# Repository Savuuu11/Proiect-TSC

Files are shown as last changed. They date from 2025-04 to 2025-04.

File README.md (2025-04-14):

# E-book Reader Open-Source
Savu Alin Ion 332CC

### Diagrama

---

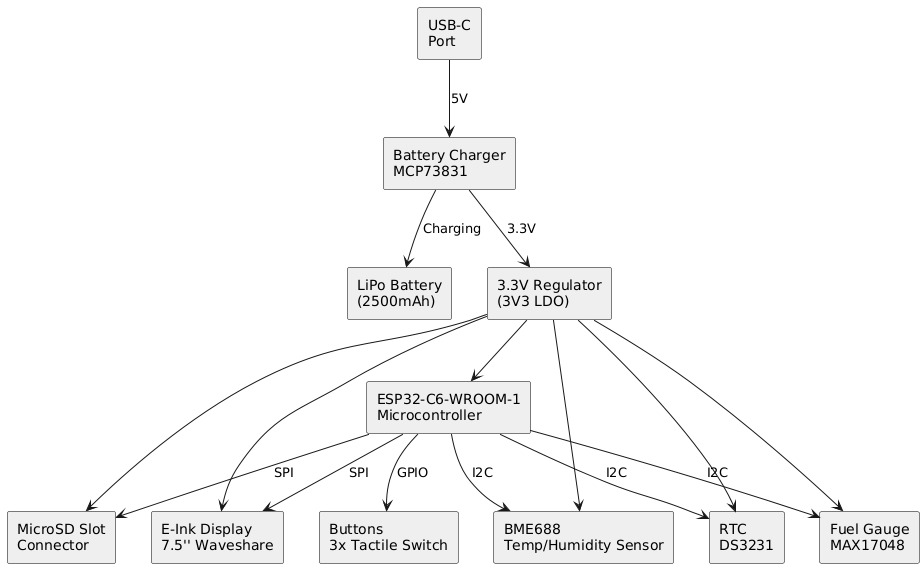
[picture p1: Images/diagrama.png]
Hardware Diagram


### BOM - Bill of Materials

---

| Name of component | Device | Check Prices | DataSheet |
|---|---|---|---|
| BOOT_BUTTON | BUTTON_CUSYOMV1 | [Link](https://industry.panasonic.com/global/en/products/control/switch/light-touch/number/evqpuj02k) | [Link](https://industry.panasonic.com/global/en/products/control/switch/light-touch/number/evqpuj02k) |
| C1 | ESP32_WROVER_EAGLE-LTSPICE_CC0402 | [Link](https://industry.panasonic.com/global/en/products/control/switch/light-touch/number/evqpuj02k) | [Link](https://industry.panasonic.com/global/en/products/control/switch/light-touch/number/evqpuj02k) |
| C1_BAT | ESP32_WROVER_EAGLE-LTSPICE_CC0402 | #N/A | #N/A |
| C1_BAT1 | EAGLE-LTSPICE_CC0402 | #N/A | #N/A |
| C1_BAT2 | EAGLE-LTSPICE_CC0402 | #N/A | #N/A |
| C2 | ESP32_WROVER_EAGLE-LTSPICE_CC0402 | #N/A | #N/A |
| C2_BAT\ | ESP32_WROVER_EAGLE-LTSPICE_CC0402 | #N/A | #N/A |
| C3 | RCL_CPOL-EUCT3528 | #N/A | #N/A |
| C4 | ESP32_WROVER_EAGLE-LTSPICE_CC0402 | #N/A | #N/A |
| C4_USB | ESP32_WROVER_EAGLE-LTSPICE_CC0402 | #N/A | #N/A |
| C5 | ESP32_WROVER_EAGLE-LTSPICE_CC0402 | #N/A | #N/A |
| C5_USB | ESP32_WROVER_EAGLE-LTSPICE_CC0402 | #N/A | #N/A |
| C6 | ESP32_WROVER_EAGLE-LTSPICE_CC0402 | #N/A | #N/A |
| C7 | ESP32_WROVER_EAGLE-LTSPICE_CC0402 | #N/A | #N/A |
| C8 | ESP32_WROVER_EAGLE-LTSPICE_CC0402 | #N/A | #N/A |
| C9 | EAGLE-LTSPICE_CC0402 | #N/A | #N/A |
| C10 | ESP32_WROVER_EAGLE-LTSPICE_CC0402 | #N/A | #N/A |
| C10_SUPERCAP | CPH3225A | [Link](https://www.snapeda.com/parts/CPH3225A/Seiko+Instruments/view-part/?ref=eda) | [Link](https://www.snapeda.com/parts/CPH3225A/Seiko+Instruments/view-part/?ref=eda) |
| CHANGE_BUTTON | BUTTON_CUSYOMV1 | [Link](https://industry.panasonic.com/global/en/products/control/switch-light-touch/number/evqpuj02k) | [Link](https://industry.panasonic.com/global/en/products/control/switch-light-touch/number/evqpuj02k) |
| CHG_LED | ADAFRUIT_LEDCHIP-LED0603 | [Link](https://www.snapeda.com/parts/KP-1608SURCK/Kingbright/view-part/?ref=search&t=LED%200603) | [Link](https://www.snapeda.com/parts/KP-1608SURCK/Kingbright/view-part/?ref=search&t=LED%200603) |
| C_DELAY | ESP32_WROVER_EAGLE-LTSPICE_CC0402 | #N/A | #N/A |
| D1 | USBLC6-2SC6Y | [Link](https://www.snapeda.com/parts/USBLC6-2SC6Y/STMicroelectronics/view-part/?ref=eda) | [Link](https://www.snapeda.com/parts/USBLC6-2SC6Y/STMicroelectronics/view-part/?ref=eda) |
| D2 | ESP32_WROVER_AVX---SD0805S020S1R0_AVX_... | [Link](https://eu.mouser.com/ProductDetail/KYOCERA-AVX/SD0805S020S1R0?qs=jCA%252BPfw4LHbpkAoSnwrdjw%3D%3D) | [Link](http://datasheets.avx.com/schottky.pdf) |
| D3 | MBR0530 | [Link](https://eu.mouser.com/ProductDetail/KYOCERA-AVX/SD0805S020S1R0?qs=jCA%252BPfw4LHbpkAoSnwrdjw%3D%3D) | [Link](https://eu.mouser.com/ProductDetail/KYOCERA-AVX/SD0805S020S1R0?qs=jCA%252BPfw4LHbpkAoSnwrdjw%3D%3D) |
| D4 | MBR0530 | [Link](https://www.snapeda.com/parts/MBR0530/Onsemi/view-part/?ref=eda) | [Link](https://www.snapeda.com/parts/MBR0530/Onsemi/view-part/?ref=eda) |
| D5 | MBR0530 | [Link](https://www.snapeda.com/parts/MBR0530/Onsemi/view-part/?ref=eda) | [Link](https://www.snapeda.com/parts/MBR0530/Onsemi/view-part/?ref=eda) |
| D6 | PGB1010603MR | [Link](https://www.snapeda.com/parts/PGB1010603MR/Littelfuse/view-part/?ref=eda) | [Link](https://www.snapeda.com/parts/PGB1010603MR/Littelfuse/view-part/?ref=eda) |
| D7 | ESP32_WROVER_AVX---SD0805S020S1R0_AVX_... | [Link](https://eu.mouser.com/ProductDetail/KYOCERA-AVX/SD0805S020S1R0?qs=jCA%252BPfw4LHbpkAoSnwrdjw%3D%3D) | [Link](http://datasheets.avx.com/schottky.pdf) |
| D8 | PGB1010603MR | [Link](https://www.snapeda.com/parts/PGB1010603MR/Littelfuse/view-part/?ref=eda) | [Link](https://www.snapeda.com/parts/PGB1010603MR/Littelfuse/view-part/?ref=eda) |
| D9 | PGB1010603MR | [Link](https://www.snapeda.com/parts/PGB1010603MR/Littelfuse/view-part/?ref=eda) | [Link](https://www.snapeda.com/parts/PGB1010603MR/Littelfuse/view-part/?ref=eda) |
| D10 | PGB1010603MR | [Link](https://www.snapeda.com/parts/PGB1010603MR/Littelfuse/view-part/?ref=eda) | [Link](https://www.snapeda.com/parts/PGB1010603MR/Littelfuse/view-part/?ref=eda) |
| D11 | PGB1010603MR | [Link](https://www.snapeda.com/parts/PGB1010603MR/Littelfuse/view-part/?ref=eda) | [Link](https://www.snapeda.com/parts/PGB1010603MR/Littelfuse/view-part/?ref=eda) |
| D12 | PGB1010603MR | [Link](https://www.snapeda.com/parts/PGB1010603MR/Littelfuse/view-part/?ref=eda) | [Link](https://www.snapeda.com/parts/PGB1010603MR/Littelfuse/view-part/?ref=eda) |
| EPD_C1 | ESP32_WROVER_EAGLE-LTSPICE_CC0402 | #N/A | #N/A |
| EPD_C2 | ESP32_WROVER_EAGLE-LTSPICE_CC0402 | #N/A | #N/A |
| EPD_C5 | ESP32_WROVER_EAGLE-LTSPICE_CC0402 | #N/A | #N/A |
| EPD_C6 | ESP32_WROVER_EAGLE-LTSPICE_CC0402 | #N/A | #N/A |
| EPD_C7 | ESP32_WROVER_EAGLE-LTSPICE_CC0402 | #N/A | #N/A |
| EPD_C8 | ESP32_WROVER_EAGLE-LTSPICE_CC0402 | #N/A | #N/A |
| EPD_C9 | ESP32_WROVER_EAGLE-LTSPICE_CC0402 | #N/A | #N/A |
| EPD_C10 | ESP32_WROVER_EAGLE-LTSPICE_CC0402 | #N/A | #N/A |
| EPD_C11 | ESP32_WROVER_EAGLE-LTSPICE_CC0402 | #N/A | #N/A |
| EPD_C12 | ESP32_WROVER_EAGLE-LTSPICE_CC0402 | #N/A | #N/A |
| IC1 | BD5229G-TR | [Link](https://componentsearchengine.com/part-view/BD5229G-TR/ROHM%20Semiconductor) | [Link](https://componentsearchengine.com/part-view/BD5229G-TR/ROHM%20Semiconductor) |
| IC4 | XC6220A331MR-G | [Link](https://componentsearchengine.com/part-view/XC6220A331MR-G/Torex) | [Link](https://componentsearchengine.com/part-view/XC6220A331MR-G/Torex) |
| J1 | FH34SRJ-24S-0.5SH_99_ | [Link](https://componentsearchengine.com/part-view/XC6220A331MR-G/Torex) | [Link](https://componentsearchengine.com/part-view/XC6220A331MR-G/Torex) |
| J2 | SAMACSYS_PARTS_USB4110-GF-A | [Link](https://componentsearchengine.com/part-view/USB4110-GF-A/GCT%20(GLOBAL%20CONNECTOR%20TECHNOLOGY) | [Link](https://componentsearchengine.com/part-view/USB4110-GF-A/GCT%20(GLOBAL%20CONNECTOR%20TECHNOLOGY) |
| J3 | QWIIC_CONNECTORJS-1MM | #N/A | #N/A |
| J4 | 112A-TAAR-R03_ATTEND | [Link](https://store.comet.srl.ro/Catalogue/Product/43497/) | [Link](https://store.comet.srl.ro/Catalogue/Product/43497/) |
| L1 | 744043680IND_4828-WE-TPC_WRE | [Link](https://eu.mouser.com/ProductDetail/Wurth-Elektronik/744043680?qs=PGXP4M47uW6VkZq%252BkzjrHA%3D%3D) | [Link](https://eu.mouser.com/ProductDetail/Wurth-Elektronik/744043680?qs=PGXP4M47uW6VkZq%252BkzjrHA%3D%3D) |
| PFMF.050.1 | ESP32C6_VARISTORCN1812 | [Link](https://www.mouser.co.uk/ProductDetail/EPCOS-TDK/B72520T0350K062?qs=dEfas%2FXlABIszF52uu7vrg%3D%3D) | [Link](https://www.mouser.co.uk/ProductDetail/EPCOS-TDK/B72520T0350K062?qs=dEfas%2FXlABIszF52uu7vrg%3D%3D) |
| Q1 | ESP32_WROVER_SPARKFUN-DISCRETESEMI_MOSFET_...| [Link](https://componentsearchengine.com/part-view/DMG2305UX-7/Diodes%20Incorporated) | [Link](https://componentsearchengine.com/part-view/DMG2305UX-7/Diodes%20Incorporated) |
| Q2 | ESP32_WROVER_SPARKFUN-DISCRETESEMI_MOSFET_...| #N/A | #N/A |
| Q3 | D8 | [Link](https://componentsearchengine.com/part-view/SI1308EDL-T1-GE3/Vishay) | [Link](https://componentsearchengine.com/part-view/SI1308EDL-T1-GE3/Vishay) |
| R1 | ESP32_WROVER_EAGLE-LTSPICE_RR0402 | #N/A | #N/A |
| R1-PINH | ESP32_WROVER_EAGLE-LTSPICE_RR0402 | #N/A | #N/A |
| R1-PINH1 | ESP32_WROVER_EAGLE-LTSPICE_RR0402 | #N/A | #N/A |
| R1_BAT | ESP32_WROVER_EAGLE-LTSPICE_RR0402 | #N/A | #N/A |
| R1_PWRUSB | ESP32_WROVER_EAGLE-LTSPICE_RR0402 | #N/A | #N/A |
| R2 | ESP32_WROVER_EAGLE-LTSPICE_RR0402 | [Link](https://componentsearchengine.com/part-view/R0402%201%25%20100%20K%20(RC0402FR-07100KL) | [Link](https://componentsearchengine.com/part-view/R0402%201%25%20100%20K%20(RC0402FR-07100KL) |
| R2-PINH | ESP32_WROVER_EAGLE-LTSPICE_RR0402 | #N/A | #N/A |
| R2-PINH1 | ESP32_WROVER_EAGLE-LTSPICE_RR0402 | #N/A | #N/A |
| R2-USB | ESP32_WROVER_EAGLE-LTSPICE_RR0402 | #N/A | #N/A |
| R2-USB1 | ESP32_WROVER_EAGLE-LTSPICE_RR0402 | #N/A | #N/A |
| R2_BAT | ESP32_WROVER_EAGLE-LTSPICE_RR0402 | #N/A | #N/A |
| R3 | ESP32_WROVER_EAGLE-LTSPICE_RR0402 | #N/A | #N/A |
| R4 | ESP32_WROVER_EAGLE-LTSPICE_RR0402 | #N/A | #N/A |
| R5 | ESP32_WROVER_EAGLE-LTSPICE_RR0402 | #N/A | #N/A |
| R6 | ESP32_WROVER_EAGLE-LTSPICE_RR0402 | #N/A | #N/A |
| R7 | ESP32_WROVER_EAGLE-LTSPICE_RR0402 | #N/A | #N/A |
| R8 | ESP32_WROVER_EAGLE-LTSPICE_RR0402 | #N/A | #N/A |
| R9 | ESP32_WROVER_EAGLE-LTSPICE_RR0402 | #N/A | #N/A |
| R10 | ESP32_WROVER_EAGLE-LTSPICE_RR0402 | #N/A | #N/A |
| RESET_BUTTON | BUTTON_CUSYOMV1 | [Link](https://industry.panasonic.com/global/en/products/control/switch/light-touch/number/evqpuj02k) | [Link](https://industry.panasonic.com/global/en/products/control/switch/light-touch/number/evqpuj02k) |
| R_BOOT | ESP32_WROVER_EAGLE-LTSPICE_RR0402 | #N/A | #N/A |
| R_CAPACITOR | ESP32_WROVER_EAGLE-LTSPICE_RR0402 | #N/A | #N/A |
| R_CHANGE | ESP32_WROVER_EAGLE-LTSPICE_RR0402 | #N/A | #N/A |
| R_CL1 | ESP32_WROVER_EAGLE-LTSPICE_RR0402 | #N/A | #N/A |
| R_RESET | ESP32_WROVER_EAGLE-LTSPICE_RR0402 | #N/A | #N/A |
| SENSOR2 | ESP32_WROVER_BME680_BME680 | [Link](https://www.snapeda.com/parts/BME680/Bosch/view-part/?welcome=home) | [Link](https://www.snapeda.com/parts/BME680/Bosch/view-part/?welcome=home) |
| SJ1 | SJ | [Link](https://grabcad.com/library/solder-jumpers-1) | [Link](https://grabcad.com/library/solder-jumpers-1) |
| TP1 | TPTP20R | #N/A | #N/A |
| TP2 | TPTP20R | #N/A | #N/A |
| TP3 | TPTP20R | #N/A | #N/A |
| TP4 | TPTP20R | #N/A | #N/A |
| TP5 | TPTP20R | #N/A | #N/A |
| TP6 | TPTP20R | #N/A | #N/A |
| TP7 | TPTP20R | #N/A | #N/A |
| TP8 | TPTP20R | #N/A | #N/A |
| TP9 | TPTP20R | #N/A | #N/A |
| TP10 | TPTP20R | #N/A | #N/A |
| TP11 | TPTP20R | #N/A | #N/A |
| TP12 | TPTP20R | #N/A | #N/A |
| TP13 | TPTP20R | #N/A | #N/A |
| TP14 | TPTP20R | #N/A | #N/A |
| TP15 | TPTP20R | #N/A | #N/A |
| TP16 | TPTP20R | #N/A | #N/A |
| TP17 | TPTP20R | #N/A | #N/A |
| U1 | W25Q512JVEIQ | [Link](https://www.snapeda.com/parts/W25Q512JVEIQ/Winbond+Electronics/view-part/?ref=eda) | [Link](https://www.snapeda.com/parts/W25Q512JVEIQ/Winbond+Electronics/view-part/?ref=eda) |
| U2 | ESP32-C6-WROOM-1-N8 | [Link](https://www.snapeda.com/parts/ESP32-C6-WROOM-1-N8/Espressif+Systems/view-part/?ref=eda) | [Link](https://www.snapeda.com/parts/ESP32-C6-WROOM-1-N8/Espressif+Systems/view-part/?ref=eda) |
| U3 | DS3231SN# | [Link](https://www.snapeda.com/parts/DS3231SN%23/Analog+Devices/view-part/?ref=eda) | [Link](https://www.snapeda.com/parts/DS3231SN%23/Analog+Devices/view-part/?ref=eda) |
| U4 | MAX17048G+T10 | [Link](https://www.snapeda.com/parts/MAX17048G+T10/Analog+Devices/view-part/?ref=eda) | [Link](https://www.snapeda.com/parts/MAX17048G+T10/Analog+Devices/view-part/?ref=eda) |
| U5 | ESP32_WROVER_SPARKFUN-IC-POWER_MCP73831 | [Link](https://eu.mouser.com/ProductDetail/Microchip-Technology/MCP73831T-2ACI-OT?qs=yUQqVecv4qvbBQBGbHx0Mw%3D%3Dcf) | [Link](https://eu.mouser.com/ProductDetail/Microchip-Technology/MCP73831T-2ACI-OT?qs=yUQqVecv4qvbBQBGbHx0Mw%3D%3Dcf) |

## Descriere Funcționalități Hardware

---

## 1. Unitate de Control – ESP32-C6  
- **Microcontroller**: `ESP32-C6-WROOM-1` (32-bit RISC-V @ 160 MHz)  
- **Memorie**:  
  - 512 KB SRAM integrat pentru procesare rapidă.  
  - 8 MB flash extern (`W25Q512JVEIQ`) pentru stocare persistentă.  
- **Conectivitate**:  
  - Wi-Fi 6 (802.11ax), Bluetooth Low Energy 5.  
  - Port USB 2.0 (full-speed).  
- **Periferice**:  
  - SPI, I²C, UART.  
  - 22 de pini GPIO configurabili.  
- **Eficiență energetică**:  
  - Moduri `sleep` și `deep sleep` (<10µA).  

---

## 2. Afișaj E-Ink (7.5 inch)  
- **Model**: Waveshare 800×480 px.  
- **Interfață**:  
  - SPI 4-fire (CS, DC, RST, BUSY).  
- **Consum energie**:  
  - **0W** în stare statică.  
  - Vârf de **25mA** la actualizare.  
- **Beneficiu**:  
  - Imagine persistentă fără alimentare.  

---

## 3. Senzor Multi-Parametru – BME680  
- **Măsurători**:  
  - Temperatură (±0.5°C), umiditate (±3%), presiune atmosferică, VOC.  
- **Interfață**: I²C @ 400 kHz.  
- **Consum**:  
  - 2.1µA în standby, 3.7mA în activitate.  
- **Avantaj**: Integrare 4-în-1 într-un singur cip.  

---

## 4. Sistem de Management al Energiei  
- **Baterie**: Li-Po 2500mAh (3.7V).  
- **Încărcare**:  
  - Controler `MCP73831` (1A via USB-C).  
- **Monitorizare**:  
  - `MAX17048` pentru nivel încărcare, tensiune și alertă.  
- **Regulator LDO**:  
  - `XC6220A331MR-G` (3.3V stabil).  

---

## 5. Interfață Utilizator – Butoane Tactile  
- **3 butoane** pentru navigare, selecție și control.  
- **Debouncing**:  
  - Hardware (circuite RC) sau software.  

---

## 6. Port USB-C  
- **Funcții**:  
  - Încărcare baterie și transfer date.  
- **Protecție**:  
  - Diodă ESD `USBLC6-2SC6Y`.  

---

## 7. Conector Qwiic pentru Expansiune  
- **4 pini standard**: VCC, GND, SDA, SCL.  
- **Scop**: Conectare senzori I²C externi (ex: senzor de lumină).  

---

## 8. Slot MicroSD  
- **Conector**: `112A-TAAR-R03`.  
- **Capacitate**: Suportă carduri microSD (stocare e-book-uri/log-uri).  
- **Interfață**: Configurabilă SPI/SD.  

---

## 9. Ceas Real-Time (DS3231)  
- **Precizie**: ±2ppm.  
- **Backup**: Supercondensator/baterie secundară.  

---

## 10. Memorie Flash Externă  
- **Model**: `W25Q512JVEIQ`.  
- **Interfață**: Quad SPI (133 MHz).  
- **Utilizare**: Firmware, setări, conținut utilizator.  

--- 

### 🔌 Interfețe și Alocare Resurse  

#### **Interfețe Utilizate**  
| Protocol | Componente Conectate |  
|---|---|
| **SPI**  | E-Paper, Memorie Flash, Card SD |  
| **I²C**  | BME680, MAX17048, DS3231, Qwiic |  
| **GPIO** | Butoane, Semnale Control E-Paper |  
| **USB**  | Alimentare + Transfer Date (USB-C) |  

---

#### **Estimare Autonomie Baterie**  
| Componentă | Consum (Activ) | Consum (Standby) |  
|---|---|---|
| **ESP32-C6** | 80 mA | <10 µA |  
| **E-Paper (refresh)**  | 25 mA | 0 mA |  
| **BME680** | 3.6 mA | 2.1 µA |  
| **MAX17048** | - | 50 µA |  
| **DS3231** | 3.5 mA | <1 µA |  
| **Total** | ~150 mA | ~100 µA |  

---

#### **Mapare Pini ESP32-C6**  
| Pin | Funcție Principală | Detalii |  
|---|---|---|
| GPIO1 | I²C SDA | Senzori BME680, MAX17048, DS3231 |  
| GPIO2 | I²C SCL | Clock pentru magistrala I²C |  
| GPIO5 | SPI MISO (E-Paper) | Recepție date afișaj |  
| GPIO6 | SPI MOSI (E-Paper) | Transmitere date afișaj |  
| GPIO7 | SPI CLK (E-Paper) | Semnal ceas SPI |  
| GPIO8 | SPI CS (E-Paper) | Selectare chip afișaj |  
| GPIO9 | DC (E-Paper) | Comutare date/comenzi |  
| GPIO10| RST (E-Paper) | Reset hardware afișaj |  
| GPIO11| BUSY (E-Paper) | Indică ocupare afișaj |  
| GPIO12| Buton #1 | Navigare "Pagina Următoare" |  
| GPIO13| Buton #2 | Navigare "Pagina Anterioară" |  
| GPIO14| Buton #3 | Meniu/Selectare |  
| GPIO15| ALERT (MAX17048) | Avertizare baterie scăzută |  
| GPIO19| SD Card CS | Selectare card MicroSD |  

---

### Conluzii
A fost un proiect foarte muncitoresc, care merita mai mult decat 2 pct.
Timp de lucru: 70h

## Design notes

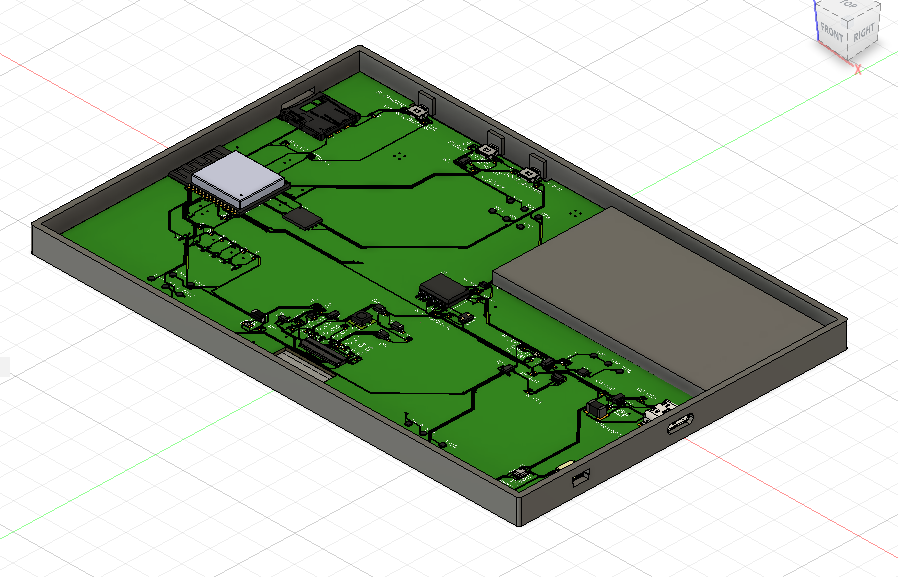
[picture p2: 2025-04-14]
Images/OpenBook Enclosure_interior.png

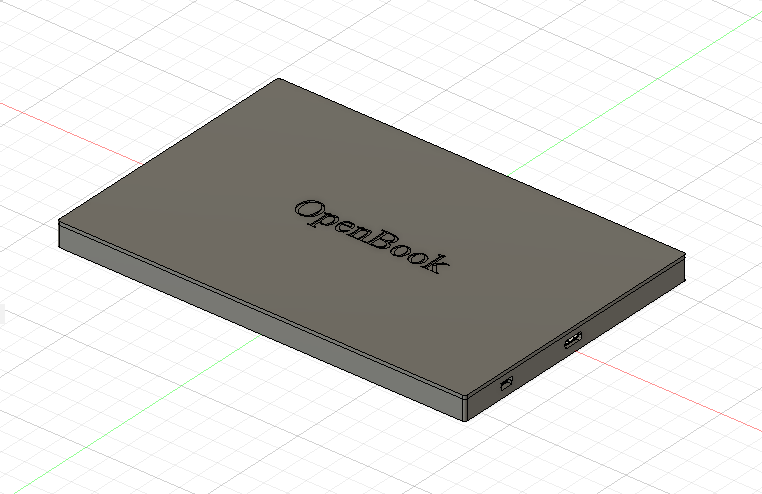
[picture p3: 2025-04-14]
Images/OpenBook Enclosure.png

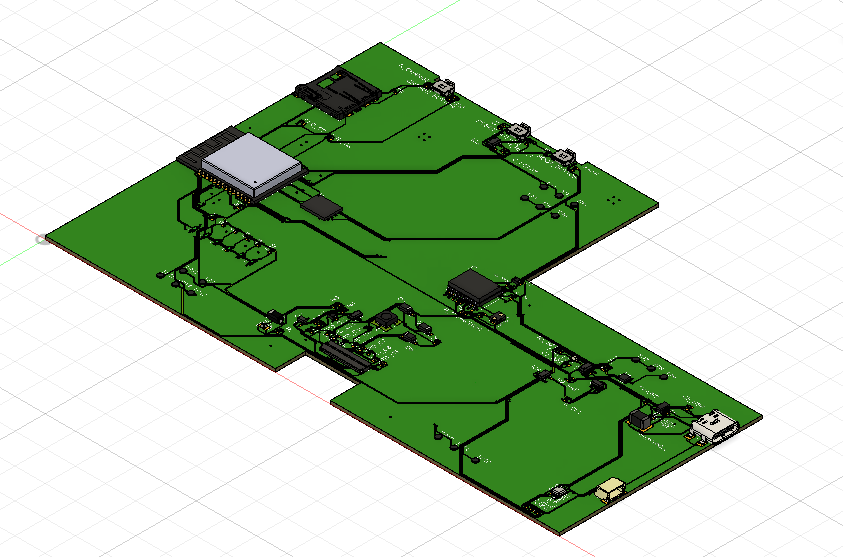
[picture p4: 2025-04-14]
Images/PCB.png

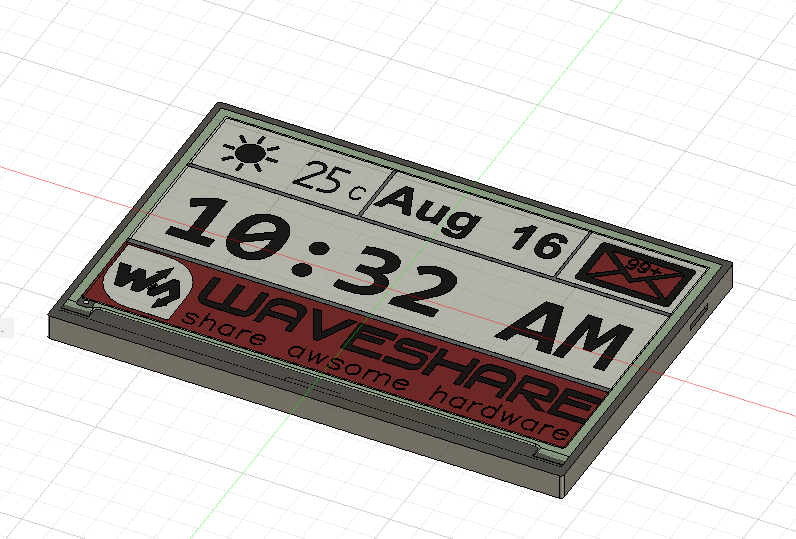
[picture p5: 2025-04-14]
Images/Display.png

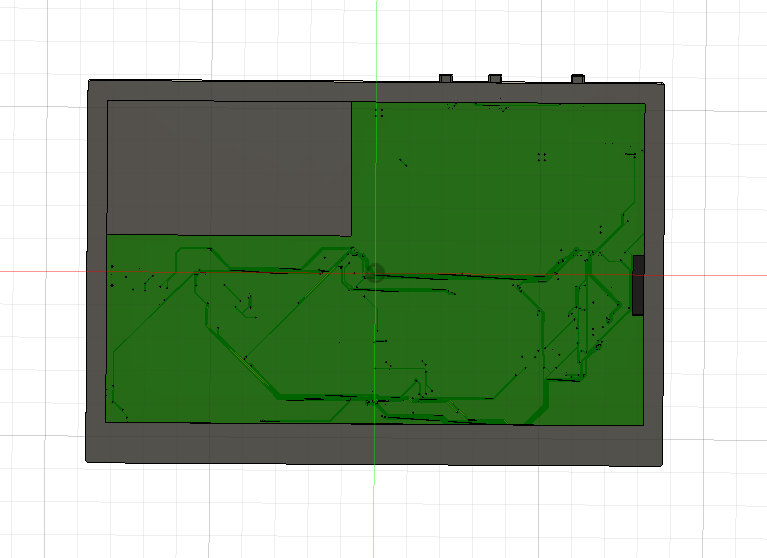
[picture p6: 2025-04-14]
Images/OpenBook Enclosure2.png

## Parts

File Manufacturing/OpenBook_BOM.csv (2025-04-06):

Qty | Value | Device | Package | Parts | Description | ARROW_PART_NUMBER | ARROW_PRICE-STOCK | AVAILABILITY | CATEGORY | CENTROID_NOT_SPECIFIED | CHECK_PRICES | COPYRIGHT | DATASHEET | DESCRIPTION | DIGIKEY_DESCRIPTION | DIGIKEY_PART_NUMBER | HEIGHT | LEAD_FREE | MANUFACTURER | MANUFACTURER_NAME | MANUFACTURER_PART_NUMBER | MF | MFR_NAME | MOUSER_PART_NUMBER | MOUSER_PRICE-STOCK | MOUSER_TESTING_PART_NUMBER | MOUSER_TESTING_PRICE-STOCK | MP | MPN | OPERATING_TEMPERATURE | PACKAGE | PACKAGE_SIZE | PACKAGE_TYPE | PART_STATUS | POPULARITY | PREFIX | PRICE | PROD_ID | PURCHASE-URL | ROHS | SERIES | SNAPEDA_LINK | SPICEMODEL | SPICEPREFIX | SUBCATEGORY | TEMPERATURE_RANGE_HIGH | TEMPERATURE_RANGE_LOW | THERMALLOSS | TOLERANCE | TP_SIGNAL_NAME | TYPE | VALUE | VOLTAGE_RATING
1 |  | ADAFRUIT_LEDCHIP-LED0603 | ADAFRUIT_CHIP-LED0603 | CHG_LED | LED
1 |  | SJ | SJ | SJ1 | SMD solder JUMPER |  |  |  |  |  |  |  |  |  |  |  |  |  |  |  |  |  |  |  |  |  |  |  |  |  |  |  |  |  | 3
1 | 0.47 | ESP32_WROVER_EAGLE-LTSPICE_RR0402 | ESP32_WROVER_EAGLE-LTSPICE_R0402 | R3 | RESISTOR, European symbol |  |  |  |  |  |  |  |  |  |  |  |  |  |  |  |  |  |  |  |  |  |  |  |  |  |  |  |  |  |  |  |  |  |  |  |  |  | NONE | R
1 | 100K | ESP32_WROVER_EAGLE-LTSPICE_RR0402 | ESP32_WROVER_EAGLE-LTSPICE_R0402 | R1_PWRUSB | RESISTOR, European symbol |  |  |  |  |  |  |  |  |  |  |  |  |  |  |  |  |  |  |  |  |  |  |  |  |  |  |  |  |  |  |  |  |  |  |  |  |  | NONE | R
7 | 100nF | EAGLE-LTSPICE_CC0402 | EAGLE-LTSPICE_C0402 | C1, C2, C6, C8, C9, C10, C_DELAY | CAPACITOR, European symbol |  |  |  |  |  |  |  |  |  |  |  |  |  |  |  |  |  |  |  |  |  |  |  |  |  |  |  |  |  |  |  |  |  |  |  |  |  | NONE | C
1 | 100nF | ESP32_WROVER_EAGLE-LTSPICE_CC0402 | ESP32_WROVER_EAGLE-LTSPICE_C0402 | C4-USB | CAPACITOR, European symbol |  |  |  |  |  |  |  |  |  |  |  |  |  |  |  |  |  |  |  |  |  |  |  |  |  |  |  |  |  |  |  |  |  |  |  |  |  | NONE | C
1 | 100uF TANT | C-POL_TANTALUM-1206(3216-METRIC) | CAPMP3216X180N | C3 | Capacitor Polarised - Generic |  |  |  | Capacitor |  |  |  |  |  |  |  |  |  |  |  |  |  |  |  |  |  |  |  |  |  |  | 1206 | SMD |  |  |  |  |  |  |  |  |  |  |  | Tantalum Capacitors |  |  |  |  |  | Polymer Capacitors
16 | 10K | ESP32_WROVER_EAGLE-LTSPICE_RR0402 | ESP32_WROVER_EAGLE-LTSPICE_R0402 | R1, R1_PINH, R1_PINH1, R2-PINH, R2-PINH1, R4, R5, R6, R7, R8, R9, R10, R_BOOT, R_CHANGE, R_CL1, R_RESET | RESISTOR, European symbol |  |  |  |  |  |  |  |  |  |  |  |  |  |  |  |  |  |  |  |  |  |  |  |  |  |  |  |  |  |  |  |  |  |  |  |  |  | NONE | R
1 | 10uF | EAGLE-LTSPICE_CC0402 | EAGLE-LTSPICE_C0402 | C7 | CAPACITOR, European symbol |  |  |  |  |  |  |  |  |  |  |  |  |  |  |  |  |  |  |  |  |  |  |  |  |  |  |  |  |  |  |  |  |  |  |  |  |  | NONE | C
1 | 112A-TAAR-R03_ATTEND | 112A-TAAR-R03_ATTEND | 112ATAARR03ATTEND | J4 | Micro SD Card Socket, Push-Push Type, Top Mount, SMT, H=1.83mm, 10u |  |  |  |  |  |  |  |  | Micro SD Card Socket | Push-Push Type | Top Mount | SMT | H=1.83mm | 10u |  |  | 1.9mm |  |  | ATTEND | 112A-TAAR-R03 ATTEND
1 | 15 | ESP32_WROVER_EAGLE-LTSPICE_RR0402 | ESP32_WROVER_EAGLE-LTSPICE_R0402 | R_CAPACITOR | RESISTOR, European symbol |  |  |  |  |  |  |  |  |  |  |  |  |  |  |  |  |  |  |  |  |  |  |  |  |  |  |  |  |  |  |  |  |  |  |  |  |  | NONE | R
1 | 1uF | EAGLE-LTSPICE_CC0402 | EAGLE-LTSPICE_C0402 | C5 | CAPACITOR, European symbol |  |  |  |  |  |  |  |  |  |  |  |  |  |  |  |  |  |  |  |  |  |  |  |  |  |  |  |  |  |  |  |  |  |  |  |  |  | NONE | C
10 | 1uF/50V | EAGLE-LTSPICE_CC0402 | EAGLE-LTSPICE_C0402 | EPD_C1, EPD_C2, EPD_C5, EPD_C6, EPD_C7, EPD_C8, EPD_C9, EPD_C10, EPD_C11, EPD_C12 | CAPACITOR, European symbol |  |  |  |  |  |  |  |  |  |  |  |  |  |  |  |  |  |  |  |  |  |  |  |  |  |  |  |  |  |  |  |  |  |  |  |  |  | NONE | C
1 | 2.2 | ESP32_WROVER_EAGLE-LTSPICE_RR0402 | ESP32_WROVER_EAGLE-LTSPICE_R0402 | R2 | RESISTOR, European symbol |  |  |  |  |  |  |  |  |  |  |  |  |  |  |  |  |  |  |  |  |  |  |  |  |  |  |  |  |  |  |  |  |  |  |  |  |  | NONE | R
1 | 200 | ESP32_WROVER_EAGLE-LTSPICE_RR0402 | ESP32_WROVER_EAGLE-LTSPICE_R0402 | R1_BAT | RESISTOR, European symbol |  |  |  |  |  |  |  |  |  |  |  |  |  |  |  |  |  |  |  |  |  |  |  |  |  |  |  |  |  |  |  |  |  |  |  |  |  | NONE | R
2 | 20V/4.2A/52mO/1.4W | ESP32_WROVER_SPARKFUN-DISCRETESEMI_MOSFET_PCH-DMG2305UX-7 | ESP32_WROVER_SPARKFUN-DISCRETESEMI_SOT23-3 | Q1, Q2 | P-channel MOSFETs |  |  |  |  |  |  |  |  |  |  |  |  |  |  |  |  |  |  |  |  |  |  |  |  |  |  |  |  |  |  |  |  | TRAN-14388 |  |  |  |  |  |  |  |  |  |  |  |  |  | 20V/4.2A/52mO/1.4W
1 | 2K | ESP32_WROVER_EAGLE-LTSPICE_RR0402 | ESP32_WROVER_EAGLE-LTSPICE_R0402 | R2_BAT | RESISTOR, European symbol |  |  |  |  |  |  |  |  |  |  |  |  |  |  |  |  |  |  |  |  |  |  |  |  |  |  |  |  |  |  |  |  |  |  |  |  |  | NONE | R
2 | 4.7uF | EAGLE-LTSPICE_CC0402 | EAGLE-LTSPICE_C0402 | C1_BAT, C2_BAT | CAPACITOR, European symbol |  |  |  |  |  |  |  |  |  |  |  |  |  |  |  |  |  |  |  |  |  |  |  |  |  |  |  |  |  |  |  |  |  |  |  |  |  | NONE | C
3 | 4.7uF | ESP32_WROVER_EAGLE-LTSPICE_CC0402 | ESP32_WROVER_EAGLE-LTSPICE_C0402 | C1-BAT1, C1_BAT2, C5_USB | CAPACITOR, European symbol |  |  |  |  |  |  |  |  |  |  |  |  |  |  |  |  |  |  |  |  |  |  |  |  |  |  |  |  |  |  |  |  |  |  |  |  |  | NONE | C
1 | 4.7uF/25V | EAGLE-LTSPICE_CC0402 | EAGLE-LTSPICE_C0402 | C4 | CAPACITOR, European symbol |  |  |  |  |  |  |  |  |  |  |  |  |  |  |  |  |  |  |  |  |  |  |  |  |  |  |  |  |  |  |  |  |  |  |  |  |  | NONE | C
2 | 5k1 | ESP32_WROVER_EAGLE-LTSPICE_RR0402 | ESP32_WROVER_EAGLE-LTSPICE_R0402 | R2-USB, R2-USB1 | RESISTOR, European symbol |  |  |  |  |  |  |  |  |  |  |  |  |  |  |  |  |  |  |  |  |  |  |  |  |  |  |  |  |  |  |  |  |  |  |  |  |  | NONE | R
1 | 68uH | 744043680IND_4828-WE-TPC_WRE | IND_4828-WE-TPC_WRE | L1 |  |  |  |  |  |  |  | Copyright (C) 2024 Ultra Librarian. All rights reserved. |  |  |  |  |  |  |  |  | 744043680 |  | Wurth Electronics
1 | BD5229G-TR | BD5229G-TR | SOT95P280X125-5N | IC1 | Voltage Detector with Adjustable Delay Time: CMOS processes are utilized to develop high precision, low current consumption CMOS reset ICs that allow arbitrary setting of the delay time. The extensive lineup includes both Nch Open Drain and CMOS output types in a wide range of detection voltages (from 2.3V to 6.0V, in 0.1V steps), enabling selection of the ideal solution based on customer requirements. In addition, the entire series is of course both lead-free and RoHS-compliant. |  |  |  |  |  |  |  |  | Voltage Detector with Adjustable Delay Time: CMOS processes are utilized to develop high precision | low current consumption CMOS reset ICs that allow arbitrary setting of the delay time. The extensive lineup includes both Nch Open Drain and CMOS output types in a wide range of detection voltages (from 2.3V to 6.0V | in 0.1V steps) | enabling selection of the ideal solution based on customer requirements. In addition | the entire series is of course both lead-free and RoHS-compliant. |  |  | 1.25mm |  |  | ROHM Semiconductor | BD5229G-TR |  |  | 755-BD5229G-TR | https://www.mouser.co.uk/ProductDetail/ROHM-Semiconductor/BD5229G-TR?qs=4kLU8WoGk0vvnhrrYwdszw%3D%3D
3 | BUTTON_CUSYOMV1 | BUTTON_CUSYOMV1 | MYBUTTON | BOOT_BUTTON, CHANGE_BUTTON, RESET_BUTTON
1 | CPH3225A | CPH3225A | CAPCP3225X100N | C10_SUPERCAP | Cap 0.011F 3.3V 1210 Flat Check availability |  |  | Not in stock |  |  | https://www.snapeda.com/parts/CPH3225A/Seiko+Instruments/view-part/?ref=eda |  |  | 11 mF (EDLC) Supercapacitor 3.3 V 1210 (3225 Metric) - - |  |  |  |  |  |  |  | Seiko Instruments |  |  |  |  |  | CPH3225A |  |  | 1210 Seiko |  |  |  |  |  | None |  | https://www.snapeda.com/api/url_track_click_mouser/?unipart_id=562593&manufacturer=Seiko Instruments&part_name=CPH3225A&search_term=None |  |  | https://www.snapeda.com/parts/CPH3225A/Seiko+Instruments/view-part/?ref=snap
1 | DS3231SN# | DS3231SN# | SOIC127P1032X265-16N | U3 | Real Time Clock Serial 16-Pin SOIC W T/R Check availability |  |  | In Stock |  |  | https://www.snapeda.com/parts/DS3231SN%23/Analog+Devices/view-part/?ref=eda |  |  | Extremely Accurate I²C-Integrated RTC/TCXO/Crystal |  |  |  |  |  |  |  | Analog Devices |  |  |  |  |  | DS3231SN# |  |  | SOIC-16 Maxim |  |  |  |  |  | None |  | https://www.snapeda.com/api/url_track_click_mouser/?unipart_id=99048&manufacturer=Analog Devices&part_name=DS3231SN#&search_term=None |  |  | https://www.snapeda.com/parts/DS3231SN%23/Analog+Devices/view-part/?ref=snap
1 | ESP32-C6-WROOM-1-N8 | ESP32-C6-WROOM-1-N8 | XCVR_ESP32-C6-WROOM-1-N8 | U2 | Check availability |  |  | In Stock |  |  | https://www.snapeda.com/parts/ESP32-C6-WROOM-1-N8/Espressif+Systems/view-part/?ref=eda |  |  | Multiprotocol Modules ESP32-C6 module | Wi-Fi 6 in 2.4 GHz band | Bluetooth 5 | Zigbee 3.0 and Thread. ESP34-WROOM Compatible - ENGINEERING SAMPLE |  |  |  |  |  |  |  | Espressif Systems |  |  |  |  |  | ESP32-C6-WROOM-1-N8 |  |  | None |  |  |  |  |  | None |  |  |  |  | https://www.snapeda.com/parts/ESP32-C6-WROOM-1-N8/Espressif+Systems/view-part/?ref=snap
1 | ESP32C6_VARISTORCN1812 | ESP32C6_VARISTORCN1812 | ESP32C6_VARISTOR_CT/CN1812 | PFMF.050.1 | VARISTOR |  |  |  |  |  |  |  |  |  |  |  |  |  |  |  |  |  |  |  |  |  |  |  |  |  |  |  |  |  | 0
2 | ESP32_WROVER_AVX---SD0805S020S1R0_AVX_SD0805S020S1R0_0_0AVX_SD0805S020S1R0_0_0 | ESP32_WROVER_AVX---SD0805S020S1R0_AVX_SD0805S020S1R0_0_0AVX_SD0805S020S1R0_0_0 | ESP32_WROVER_AVX---SD0805S020S1R0_AVX_SD0805S020S1R0_0 | D2, D7 | Schottky Barrier Rectifier Diode |  |  |  |  | No |  |  | http://datasheets.avx.com/schottky.pdf |  | DIODE SCHOTTKY 20V 1A 0805 | 478-7800-1-ND |  | yes |  |  |  | AVX |  | 581-SD0805S020S1R0 |  |  |  |  |  |  | 0805 (2012 metric) |  |  |  |  | D |  |  |  | yes |  |  |  |  |  | +125°C | -55°C
1 | ESP32_WROVER_BME680_BME680 | ESP32_WROVER_BME680_BME680 | ESP32_WROVER_BME680_PSON80P300X300X100-8N | SENSOR2 | Integrated Environmental Unit |  |  | Unavailable |  |  |  |  |  | Integrated Environmental Unit |  |  |  |  |  |  |  | Bosch Sensortec |  |  |  |  |  | BME680 |  |  | LGA-8 Bosch Tools |  |  |  |  |  | None
1 | ESP32_WROVER_SPARKFUN-IC-POWER_MCP73831 | ESP32_WROVER_SPARKFUN-IC-POWER_MCP73831 | ESP32_WROVER_SPARKFUN-IC-POWER_SOT23-5 | MCP73831 | MCP73831T Li-Ion, Li-Pol Controller |  |  |  |  |  |  |  |  |  |  |  |  |  |  |  |  |  |  |  |  |  |  |  |  |  |  |  |  |  |  |  |  | IC-09995
1 | FH34SRJ-24S-0.5SH_99_ | FH34SRJ-24S-0.5SH_99_ | FH34SRJ24S05SH99 | J1 | (0.50mm) Surface Mount, Right Angle |  |  |  |  |  |  |  |  | 24 Position FFC | FPC Connector Contacts | (0.50mm) Surface Mount | Right Angle |  |  | 1.1mm |  |  | Hirose | FH34SRJ-24S-0.5SH(99) |  |  | 798-FH34SRJ24S05SH99 | https://www.mouser.co.uk/ProductDetail/Hirose-Connector/FH34SRJ-24S-0.5SH99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
1 | MAX17048G+T10 | MAX17048G+T10 | SON50P200X200X80-9N | U4 | Check availability |  |  | In Stock |  |  | https://www.snapeda.com/parts/MAX17048G+T10/Analog+Devices/view-part/?ref=eda |  |  | 3µA 1-Cell/2-Cell Fuel Gauge with ModelGauge |  |  |  |  |  |  |  | Analog Devices |  |  |  |  |  | MAX17048G+T10 |  |  | TDFN-8 Maxim |  |  |  |  |  | None |  | https://www.snapeda.com/api/url_track_click_mouser/?unipart_id=329239&manufacturer=Analog Devices&part_name=MAX17048G+T10&search_term=None |  |  | https://www.snapeda.com/parts/MAX17048G+T10/Analog+Devices/view-part/?ref=snap
3 | MBR0530 | MBR0530 | SOD3716X135N | D3, D4, D5 | ON SEMICONDUCTOR - MBR0530 - DIODE, SCHOTTKY, 0.5A, 30V, SOD-123 |  |  | In Stock |  |  | https://www.snapeda.com/parts/MBR0530/Onsemi/view-part/?ref=eda |  |  | Diode Schottky 30 V 500mA Surface Mount SOD-123 |  |  |  |  |  |  |  | ON Semiconductor |  |  |  |  |  | MBR0530 |  |  | SOD-123-2 ON Semiconductor |  |  |  |  |  | None |  | https://www.snapeda.com/api/url_track_click_mouser/?unipart_id=179458&manufacturer=ON Semiconductor&part_name=MBR0530&search_term=None |  |  | https://www.snapeda.com/parts/MBR0530/Onsemi/view-part/?ref=snap
6 | PGB1010603MR | PGB1010603MR | DIOC1608X36N | D6, D8, D9, D10, D11, D12 | Check availability |  |  | In Stock |  |  | https://www.snapeda.com/parts/PGB1010603MR/Littelfuse/view-part/?ref=eda |  |  | 150V (Typ) Clamp - Ipp Tvs Diode Surface Mount 0603 (1608 Metric) |  |  |  |  |  |  |  | Littelfuse Inc. |  |  |  |  |  | PGB1010603MR |  |  | 0603 Littelfuse Inc. |  |  |  |  |  | None |  | https://www.snapeda.com/api/url_track_click_mouser/?unipart_id=5659453&manufacturer=Littelfuse Inc.&part_name=PGB1010603MR&search_term=None |  |  | https://www.snapeda.com/parts/PGB1010603MR/Littelfuse/view-part/?ref=snap
1 | QWIIC_RIGHT_ANGLE | QWIIC_CONNECTORJS-1MM | JST04_1MM_RA | J3 | SparkFun I2C Standard Qwiic Connector |  |  |  |  |  |  |  |  |  |  |  |  |  |  |  |  |  |  |  |  |  |  |  |  |  |  |  |  |  |  |  |  | CONN-13694 |  |  |  |  |  |  |  |  |  |  |  |  |  | QWIIC_RIGHT_ANGLE
1 | SAMACSYS_PARTS_USB4110-GF-A | SAMACSYS_PARTS_USB4110-GF-A | SAMACSYS_PARTS_USB4110GFA | J2 | CONN USB 2.0 TYPE-C R/A SMT |  |  |  |  |  |  |  |  | CONN USB 2.0 TYPE-C R/A SMT |  |  | 3.26mm |  |  | GCT (GLOBAL CONNECTOR TECHNOLOGY) | USB4110-GF-A |  |  | 640-USB4110-GF-A | https://www.mouser.co.uk/ProductDetail/GCT/USB4110-GF-A?qs=KUoIvG%2F9IlYiZvIXQjyJeA%3D%3D
1 | SI1308EDL-T1-GE3 | SI1308EDL-T1-GE3 | SOT65P210X110-3N | Q3 | MOSFET N-Ch 30V 1.5A TrenchFET SC70 Vishay Si1308EDL-T1-GE3 N-channel MOSFET Transistor, 1.5 A, 30 V, 3-Pin SC-70 |  |  | In Stock |  |  | https://www.snapeda.com/parts/SI1308EDL-T1-GE3/Vishay+Siliconix/view-part/?ref=eda |  |  | Si1308EDL-T1-GE3 N-channel MOSFET Transistor | 1.5 A | 30 V | 3-Pin SC-70 | Siliconix / Vishay SI1308EDL-T1-GE3 |  |  |  |  |  |  |  | Vishay Siliconix |  |  |  |  |  | SI1308EDL-T1-GE3 |  |  | SOT-323 Vishay Semiconductor |  |  |  |  |  | None |  | https://www.snapeda.com/api/url_track_click_mouser/?unipart_id=274603&manufacturer=Vishay Siliconix&part_name=SI1308EDL-T1-GE3&search_term=None |  |  | https://www.snapeda.com/parts/SI1308EDL-T1-GE3/Vishay+Siliconix/view-part/?ref=snap
17 | TPTP20R | TPTP20R | TP20R | TP1, TP2, TP3, TP4, TP5, TP6, TP7, TP8, TP9, TP10, TP11, TP12, TP13, TP14, TP15, TP16, TP17 | Test pad |  |  |  |  |  |  |  |  |  |  |  |  |  |  |  |  |  |  |  |  |  |  |  |  |  |  |  |  |  | 2
1 | USBLC6-2SC6Y | USBLC6-2SC6Y | SOT95P280X145-6N | D1 | Low Cap. ESD Protection Auto SOT-23-6 STMicroelectronics USBLC6-2SC6Y, Dual Uni-Directional TVS Diode Array, 6-Pin SOT-23 |  |  | In Stock |  |  | https://www.snapeda.com/parts/USBLC6-2SC6Y/STMicroelectronics/view-part/?ref=eda |  |  | 17V Clamp 5A (8/20µs) Ipp Tvs Diode Surface Mount SOT-23-6 |  |  |  |  |  |  |  | STMicroelectronics |  |  |  |  |  | USBLC6-2SC6Y |  |  | SOT-23-6 STMicroelectronics |  |  |  |  |  | None |  |  |  |  | https://www.snapeda.com/parts/USBLC6-2SC6Y/STMicroelectronics/view-part/?ref=snap
1 | W25Q512JVEIQ | W25Q512JVEIQ | SON127P600X800X80-9N | U1 | Check availability |  |  | In Stock |  |  | https://www.snapeda.com/parts/W25Q512JVEIQ/Winbond+Electronics/view-part/?ref=eda |  |  | FLASH - NOR Memory IC 512Mb (64M x 8) SPI - Quad I/O 133 MHz 8-WSON (8x6) |  |  |  |  |  |  |  | Winbond Electronics |  |  |  |  |  | W25Q512JVEIQ |  |  | Package |  |  |  |  |  | None |  |  |  |  | https://www.snapeda.com/parts/W25Q512JVEIQ/Winbond+Electronics/view-part/?ref=snap
1 | XC6220A331MR-G | XC6220A331MR-G | SOT95P280X120-5N | IC4 | LDO Voltage Regulators |  |  |  |  |  |  |  |  | LDO Voltage Regulators |  |  | 1.2mm |  |  | Torex | XC6220A331MR-G |  |  | 865-XC6220A331MR-G | https://www.mouser.co.uk/ProductDetail/Torex-Semiconductor/XC6220A331MR-G?qs=AsjdqWjXhJ8ZSWznL1J0gg%3D%3D

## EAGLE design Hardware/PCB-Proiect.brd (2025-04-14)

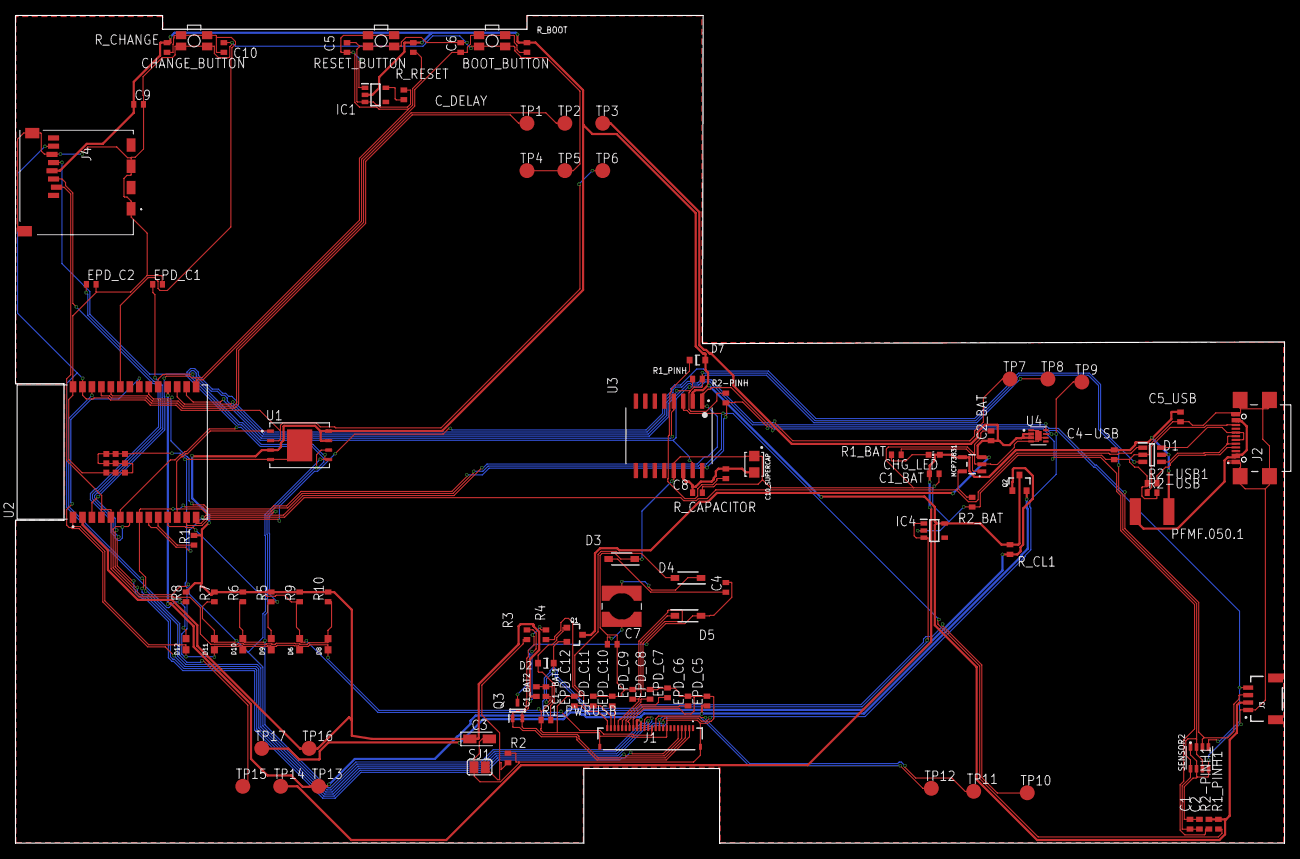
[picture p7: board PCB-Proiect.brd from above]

Board: 2 copper layers, 170.2 x 111.0 mm, 103 parts (0 on the bottom side), 58 nets.

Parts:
BOOT_BUTTON: BUTTON_CUSYOMV1; MYBUTTON
C1, C2, C6, C8, C9, C10: 100nF; EAGLE-LTSPICE_C0402
C1-BAT1, C1_BAT2, C5_USB: 4.7uF; ESP32_WROVER_EAGLE-LTSPICE_C0402
C1_BAT, C2_BAT: 4.7uF; EAGLE-LTSPICE_C0402
C3: 100uF TANT; CAPMP3216X180N
C4: 4.7uF/25V; EAGLE-LTSPICE_C0402
C4-USB: 100nF; ESP32_WROVER_EAGLE-LTSPICE_C0402
C5: 1uF; EAGLE-LTSPICE_C0402
C7: 10uF; EAGLE-LTSPICE_C0402
C10_SUPERCAP: CPH3225A; CAPCP3225X100N
CHANGE_BUTTON: BUTTON_CUSYOMV1; MYBUTTON
CHG_LED: ADAFRUIT_CHIP-LED0603
C_DELAY: 100nF; EAGLE-LTSPICE_C0402
D1: USBLC6-2SC6Y; SOT95P280X145-6N
D2, D7: ESP32_WROVER_AVX---SD0805S020S1R0_AVX_SD0805S020S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; ESP32_WROVER_AVX---SD0805S020S1R0_AVX_SD0805S020S1R0_0
D3, D4, D5: MBR0530; SOD3716X135N
D6, D8, D9, D10, D11, D12: PGB1010603MR; DIOC1608X36N
EPD_C1, EPD_C2, EPD_C5, EPD_C6, EPD_C7, EPD_C8, EPD_C9, EPD_C10, EPD_C11, EPD_C12: 1uF/50V; EAGLE-LTSPICE_C0402
IC1: BD5229G-TR; SOT95P280X125-5N
IC4: XC6220A331MR-G; SOT95P280X120-5N
J1: FH34SRJ-24S-0.5SH_99_; FH34SRJ24S05SH99
J2: SAMACSYS_PARTS_USB4110-GF-A; SAMACSYS_PARTS_USB4110GFA
J3: QWIIC_RIGHT_ANGLE; JST04_1MM_RA
J4: 112A-TAAR-R03_ATTEND; 112ATAARR03ATTEND
L1: 68uH; IND_4828-WE-TPC_WRE
MCP73831: ESP32_WROVER_SPARKFUN-IC-POWER_MCP73831; ESP32_WROVER_SPARKFUN-IC-POWER_SOT23-5
PFMF.050.1: ESP32C6_VARISTORCN1812; ESP32C6_VARISTOR_CT/CN1812
Q1, Q2: 20V/4.2A/52mΩ/1.4W; ESP32_WROVER_SPARKFUN-DISCRETESEMI_SOT23-3
Q3: SI1308EDL-T1-GE3; SOT65P210X110-3N
R1, R1_PINH, R1_PINH1, R2-PINH, R2-PINH1, R4, R5, R6, R7, R8, R9, R10: 10K; ESP32_WROVER_EAGLE-LTSPICE_R0402
R1_BAT: 200; ESP32_WROVER_EAGLE-LTSPICE_R0402
R1_PWRUSB: 100K; ESP32_WROVER_EAGLE-LTSPICE_R0402
R2: 2.2; ESP32_WROVER_EAGLE-LTSPICE_R0402
R2-USB, R2-USB1: 5k1; ESP32_WROVER_EAGLE-LTSPICE_R0402
R2_BAT: 2K; ESP32_WROVER_EAGLE-LTSPICE_R0402
R3: 0.47; ESP32_WROVER_EAGLE-LTSPICE_R0402
RESET_BUTTON: BUTTON_CUSYOMV1; MYBUTTON
R_BOOT: 10K; ESP32_WROVER_EAGLE-LTSPICE_R0402
R_CAPACITOR: 15; ESP32_WROVER_EAGLE-LTSPICE_R0402
R_CHANGE: 10K; ESP32_WROVER_EAGLE-LTSPICE_R0402
R_CL1: 10K; ESP32_WROVER_EAGLE-LTSPICE_R0402
R_RESET: 10K; ESP32_WROVER_EAGLE-LTSPICE_R0402
SENSOR2: ESP32_WROVER_BME680_BME680; ESP32_WROVER_BME680_PSON80P300X300X100-8N
SJ1: SJ
TP1, TP2, TP3, TP4, TP5, TP6, TP7, TP8, TP9, TP10, TP11, TP12, TP13, TP14, TP15, TP16, TP17: TPTP20R; TP20R
U1: W25Q512JVEIQ; SON127P600X800X80-9N
U2: ESP32-C6-WROOM-1-N8; XCVR_ESP32-C6-WROOM-1-N8
U3: DS3231SN#; SOIC127P1032X265-16N
U4: MAX17048G+T10; SON50P200X200X80-9N

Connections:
3V3: C1_BAT2.1, C3.1, C9.1, D7.2, IC1.2, IC4.5, J3.2, J4.P4, Q2.3, R1.2, R1_PINH1.2, R2-PINH1.2, R5.2, R6.2, R7.2, R8.2, R9.2, R10.2, R_BOOT.2, R_CHANGE.2, R_CL1.2, R_RESET.2, TP16.TP, U1.3, U1.7, U1.8, U2.2, U3.2
32KHZ: R2-PINH1.1, U2.9, U3.1
DN: D1.4, J2.A7, J2.B7
DP: D1.6, J2.A6, J2.B6
EPD_3V3: EPD_C5.1, J1.15, J1.16, Q2.2, TP17.TP
EPD_3V3_C: Q2.1, R_CL1.1, TP13.TP, U2.18
EPD_BUSY: J1.9, TP9.TP, U2.26
EPD_CS: D6.2, J1.12, R9.1, TP10.TP, U2.11
EPD_DC: J1.11, TP11.TP
EPD_RST: J1.10, TP12.TP, U2.21
FLASH_CS: D9.2, R5.1, U1.1, U2.12
GDR: J1.2, Q3.1, R4.2
GND: BOOT_BUTTON.1, BOOT_BUTTON.2, C1.2, C1-BAT1.2, C1_BAT.2, C1_BAT2.2, C2.2, C2_BAT.2, C3.2, C4-USB.1, C5.2, C5_USB.1, C6.2, C7.2, C8.2, C9.2, C10.2, C10_SUPERCAP.1, CHANGE_BUTTON.1, CHANGE_BUTTON.2, C_DELAY.2, D1.2, D3.1, D6.1, D8.1, D9.1, D10.1, D11.1, D12.1, EPD_C1.2, EPD_C2.2, EPD_C5.2, EPD_C6.2, EPD_C7.2, EPD_C8.2, EPD_C9.2, EPD_C10.2, EPD_C11.2, EPD_C12.2, IC1.3, IC4.2, J1.8, J1.17, J1.MP1, J1.MP2, J2.A1, J2.A12, J2.B1, J2.B12, J2.MP1, J2.MP2, J2.MP3, J2.MP4, J3.1, J4.G1, J4.G2, J4.G3, J4.G4, J4.P6, MCP73831.2, R1_PWRUSB.1, R2.2, R2-USB.2, R2-USB1.1, R2_BAT.1, R4.1, RESET_BUTTON.1, RESET_BUTTON.2, SENSOR2.1, SENSOR2.5, SENSOR2.7, SJ1.1, TP4.TP, TP5.TP, U1.4, U1.9, U2.1, U2.28, U2.29_1, U2.29_2, U2.29_3, U2.29_4, U2.29_5, U2.29_6, U2.29_7, U2.29_8, U2.29_9, U3.13, U4.1, U4.4, U4.6, U4.9
GPI08: R1.1, U2.10
I2C_PW: C1.1, C2.1, R1_PINH.2, R2-PINH.2, SENSOR2.2, SENSOR2.6, SENSOR2.8, U2.17
INT_RTC: R1_PINH1.1, TP15.TP, U2.8, U3.3
IO/BOOT: BOOT_BUTTON.3, BOOT_BUTTON.4, C6.1, R_BOOT.1, U2.15
IO/CHANGE: C10.1, CHANGE_BUTTON.3, CHANGE_BUTTON.4, R_CHANGE.1, U2.23
MISO: D12.2, J4.P7, R8.1, TP6.TP, U1.2, U2.27
MOSI: D11.2, J1.14, J4.P3, R7.1, TP7.TP, U1.5, U2.7
unnamed: D2.2, Q1.1, R1_PWRUSB.2
unnamed: J2.B5, R2-USB.1
unnamed: J2.A5, R2-USB1.2
unnamed: C7.1, L1.2
unnamed: C1-BAT1.1, D2.1, IC4.1, IC4.3, Q1.2
unnamed: D4.1, L1.1
unnamed: C4.1, D3.2
unnamed: CHG_LED.C, R1_BAT.1
unnamed: MCP73831.1, R1_BAT.2
unnamed: MCP73831.5, R2_BAT.2
unnamed: C_DELAY.1, IC1.5
unnamed: EPD_C12.1, J1.24
unnamed: EPD_C10.1, J1.22
unnamed: EPD_C8.1, J1.20
unnamed: EPD_C7.1, J1.19
unnamed: D7.1, R_CAPACITOR.1
unnamed: EPD_C6.1, J1.18
unnamed: EPD_C2.1, J1.5
unnamed: EPD_C1.1, J1.4
PREVGH: D5.1, EPD_C9.1, J1.21
PREVGL: D4.2, EPD_C11.1, J1.23
RESE: J1.3, Q3.2, R3.2
RESE': R2.1, R3.1, SJ1.2
RESET: C5.1, IC1.1, RESET_BUTTON.3, RESET_BUTTON.4, R_RESET.1, U2.3
RTC_RST: U2.16, U3.4
RX: TP2.TP, U2.24
SCK: D10.2, J1.13, J4.P5, R6.1, TP8.TP, U1.6, U2.6
SCL: J3.4, R2-PINH.1, SENSOR2.4, U2.20, U3.16, U4.7
SDA: J3.3, R1_PINH.1, SENSOR2.3, U2.19, U3.15, U4.8
SRC: C4.2, D5.2, Q3.3
SS_SD: D8.2, J4.P2, R10.1, U2.4, U2.5
TX: TP1.TP, U2.25
USB_D+: D1.1, U2.14
USB_D-: D1.3, U2.13
VBAT: C2_BAT.1, MCP73831.3, Q1.3, TP3.TP, U4.2, U4.3
VBUS: C1_BAT.1, C4-USB.2, C5_USB.2, CHG_LED.A, D1.5, MCP73831.4, PFMF.050.1.2, TP14.TP
VRTC: C8.1, C10_SUPERCAP.2, R_CAPACITOR.2, U3.14
VUSB: J2.A4, J2.A9, J2.B4, J2.B9, PFMF.050.1.1

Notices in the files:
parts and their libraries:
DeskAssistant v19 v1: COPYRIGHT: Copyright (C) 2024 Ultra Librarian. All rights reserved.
